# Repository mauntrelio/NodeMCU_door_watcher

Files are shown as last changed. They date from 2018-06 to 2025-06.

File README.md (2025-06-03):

# Tür Beobachtung: DIY Door Alarm System

Welcome to the Tür Beobachtung project! This is a DIY door alarm system I created in 2019 to help my in-laws keep their bike shed door securely closed during the night at their countryside retreat. Over time, I've enhanced it with new features and improvements.

## Project Overview

The Tür Beobachtung project combines hardware and software to create an effective door monitoring solution. It's designed to alert the user with both audio and visual signals if the door remains open during specific times, mostly at night. We utilize an ESP8266 microcontroller with added functionalities including notifications via Pushbullet and time synchronization from the start. Over time, improvements have included a 3D-printed box, a web interface running directly on the microcontroller, TOTP-based authentication for an HTTPS gateway, and fine-tuned alarm management.

## List of Materials

- 1 ESP8266 Microcontroller
- 1 5V Power Supply
- 1 Magnetic Sensor
- 1 Magnet
- 1 LCD Panel HD44780 with I2C Controller
- 1 Light (LED)
- 1 Voltage Booster (5V to 12V)
- 2 Transistors
- 2 Diodes
- 2 Resistors (1kΩ)
- 1 Resistor (200Ω)
- 1 Buzzer Module
- 1 LED
- 1 Main Switch
- 4 Small Switches
- Various Cables

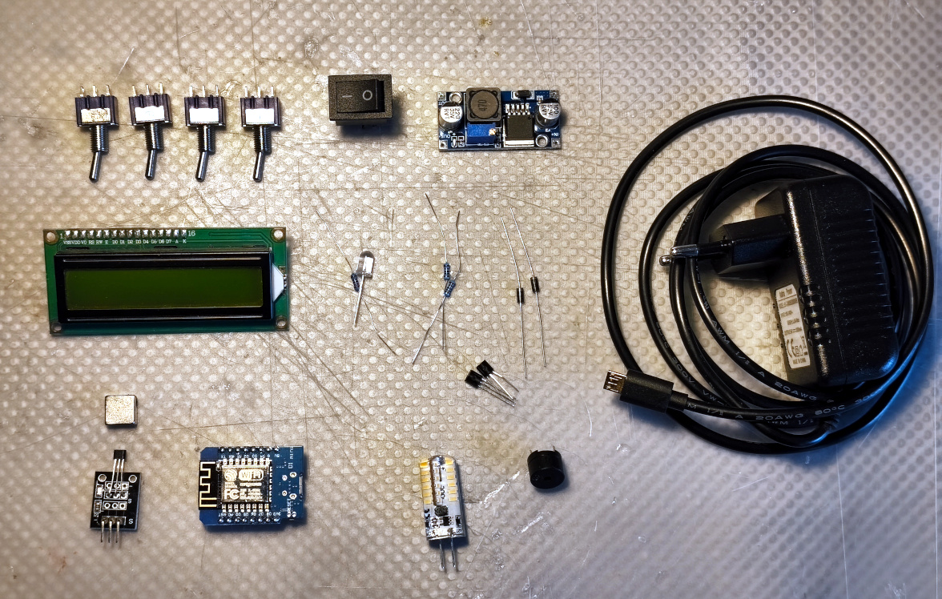
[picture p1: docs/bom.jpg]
List of Materials


## Installation and Usage

### Code and Compilation

The code for the Tür Beobachtung project is written in C and designed to be compiled and uploaded to the microcontroller using [PlatformIO](https://platformio.org/).

To be able to send Pushbullet notification without using HTTPS, a gateway server in HTTP with a PHP script sending the requests to Pushbullet in HTTPS is needed. Authentication over the unsafe HTTP channel is done via TOTP.

- **`src` folder**: Contains the source code for the microcontroller (ESP8266).
- **`web` folder**: Contains files for the web server that acts as a gateway for sending notifications via Pushbullet or to perform other HTTPS requests that the microcontroller cannot handle directly.
- **`data` folder**: Contains the file system for the web interface to be uploaded onto the microcontroller.
- **`docs` folder**: Contains some pictures of the project and the electrical schematics drawn using Fritzing.

### Electrical Schematic

The project's electrical schematic, drawn using [Fritzing](http://fritzing.org/), is included to provide a clear and organized guide to building and assembling the hardware components.

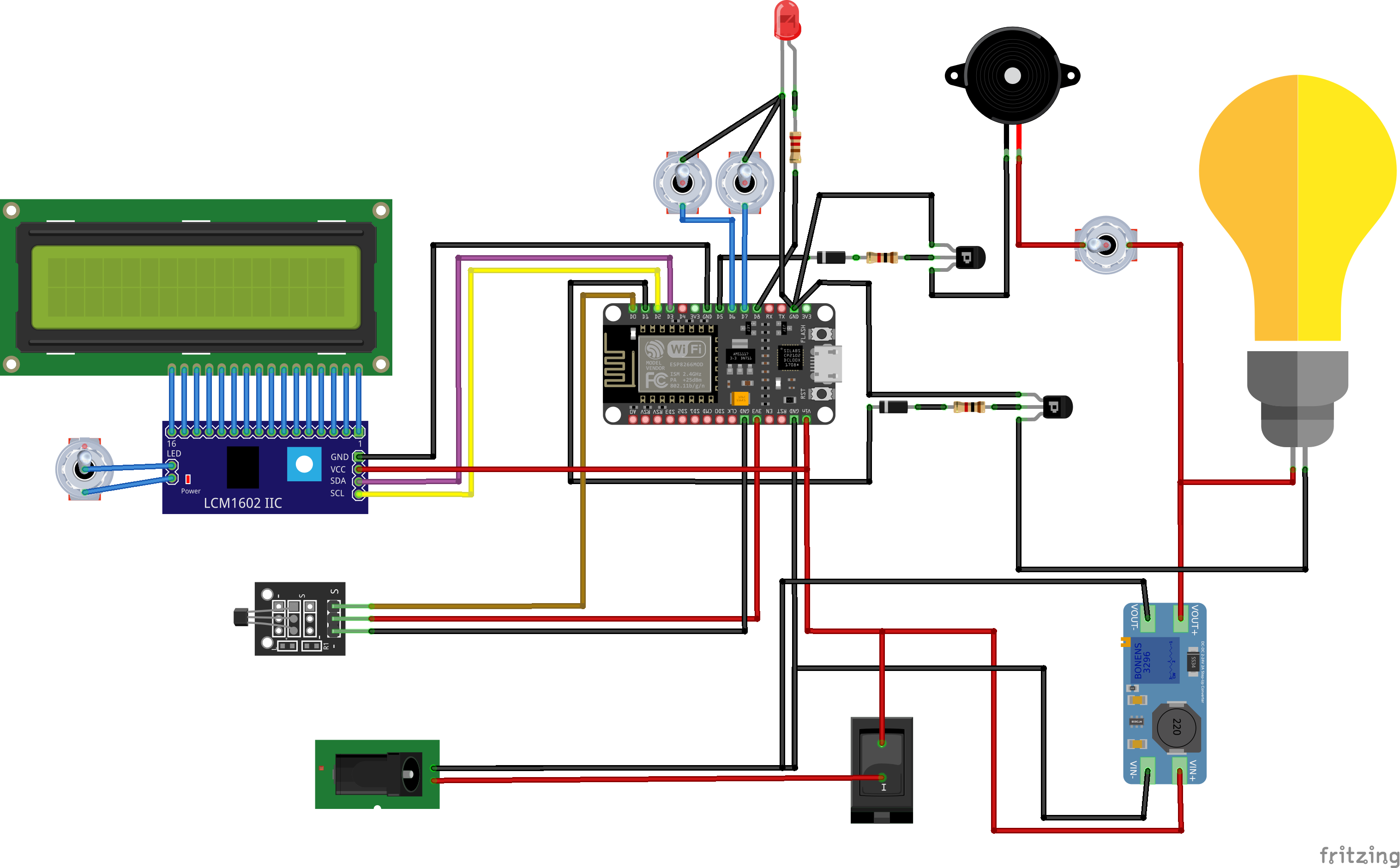
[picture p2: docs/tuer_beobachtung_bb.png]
Electrical Schematic


## Features

- **Automatic Time Synchronization**: Ensures the alarm activates at the correct hours.
- **Push Notifications**: Alerts are sent directly to your mobile device via Pushbullet if the door is left open.
- **Manual Override Switches**: Allow for manual control over the alarm system and lighting.
- **TOTP Authentication**: Adds a layer of security for server communications.

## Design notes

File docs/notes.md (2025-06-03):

# Tür Beobacthung BOM

- ESP8266 (nodeMCU)
- Alimentatore 5V
- Interruttore
- Booster 12V (per luce)
- Luce (esterna)
- Buzzer (esterno)
- 2 diode (light + buzzer switch)
- 2 x 1kOhm resistor (light + buzzer switch)
- 2 npn BJT (light + buzzer switch)
- 200Ohm resistor
- 1 red led
- 3 swicthes (alarm, light, display)
- 1 magnetic sensor
- 1 magnet
- 1 HD44780 1602 LCD Module

Connected PINs

D0, 3V (sensor, input)
D1 (light transistor, output)
D5 (buzzer transistor, output)
D2, D3 (i2c)
D6 (switch light on/off, input)
D7 (switch alarm on/off, input)
D8 (led alarm, output)

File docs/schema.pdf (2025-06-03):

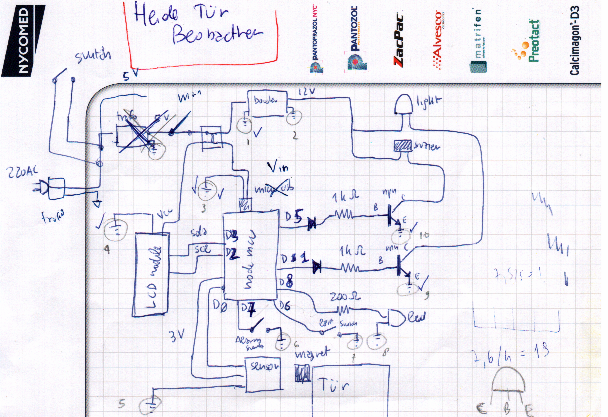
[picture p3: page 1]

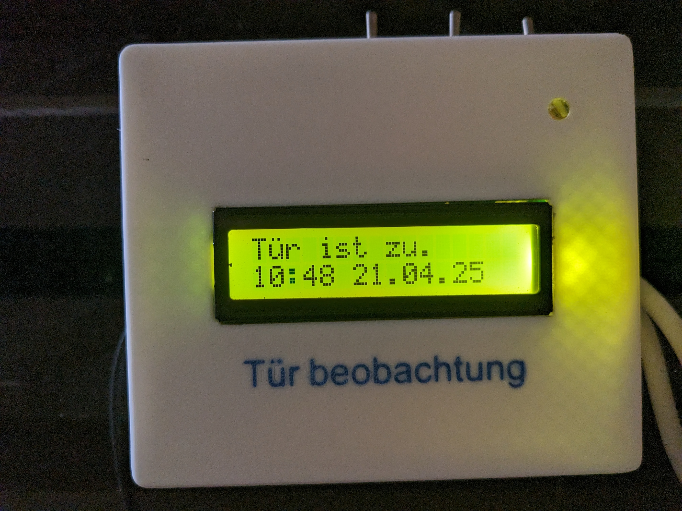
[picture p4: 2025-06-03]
docs/PXL_20250421_084856044_Mau.jpg

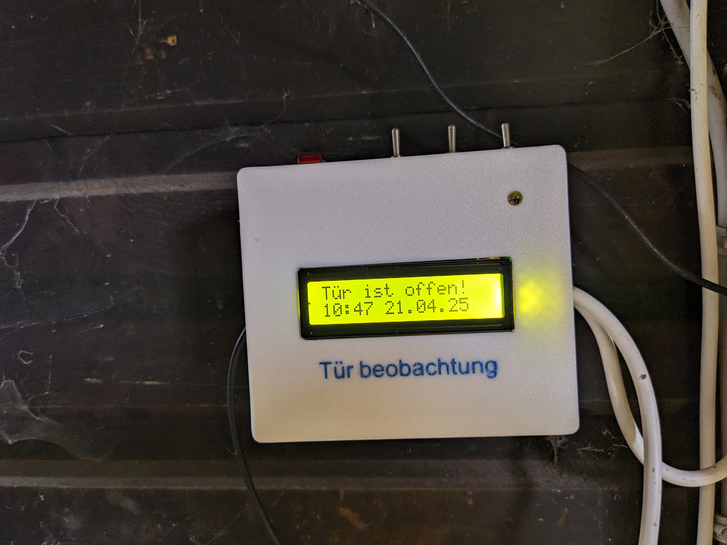
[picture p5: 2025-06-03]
docs/PXL_20250421_084728889_Mau.jpg

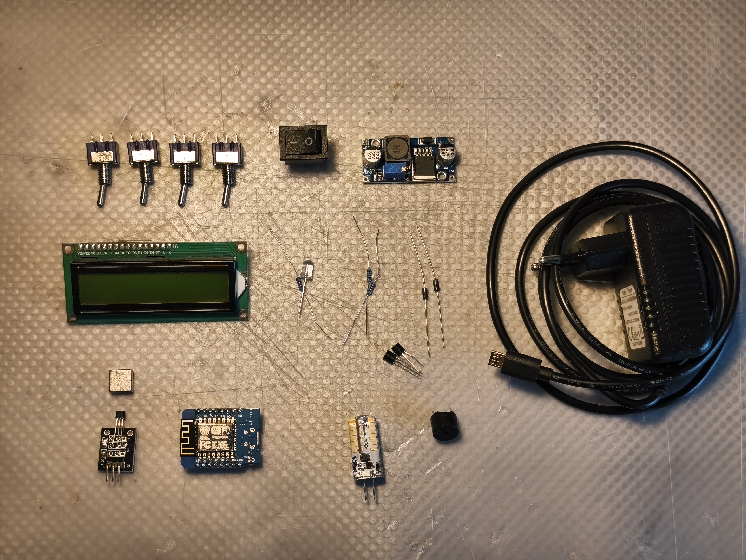
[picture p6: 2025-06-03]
docs/IMG_20250526_201353_Mau.jpg

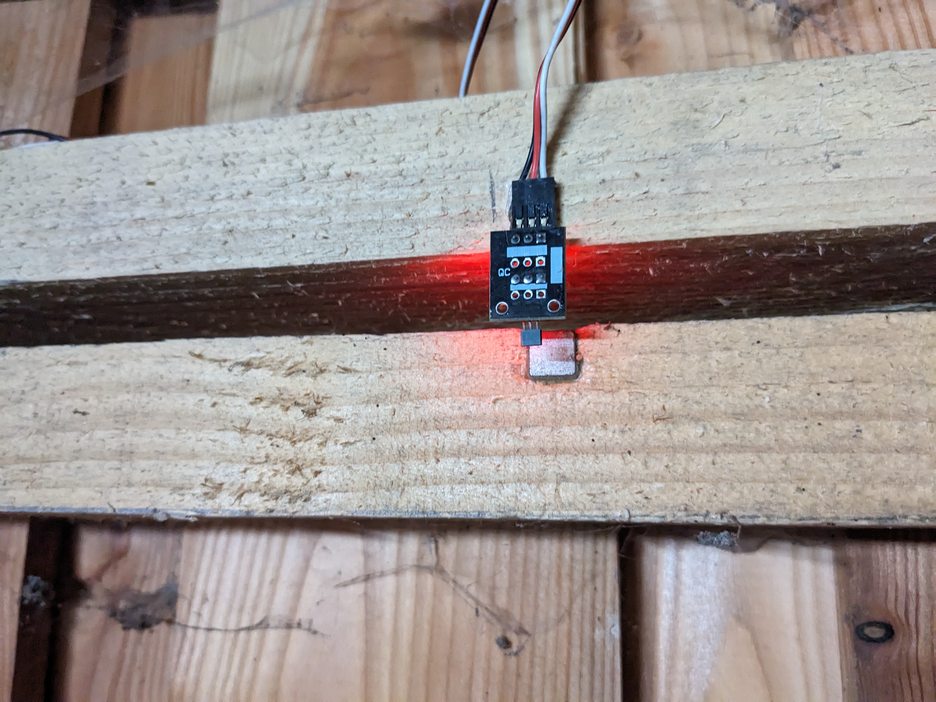
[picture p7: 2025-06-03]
docs/PXL_20250421_084847016_Mau.jpg

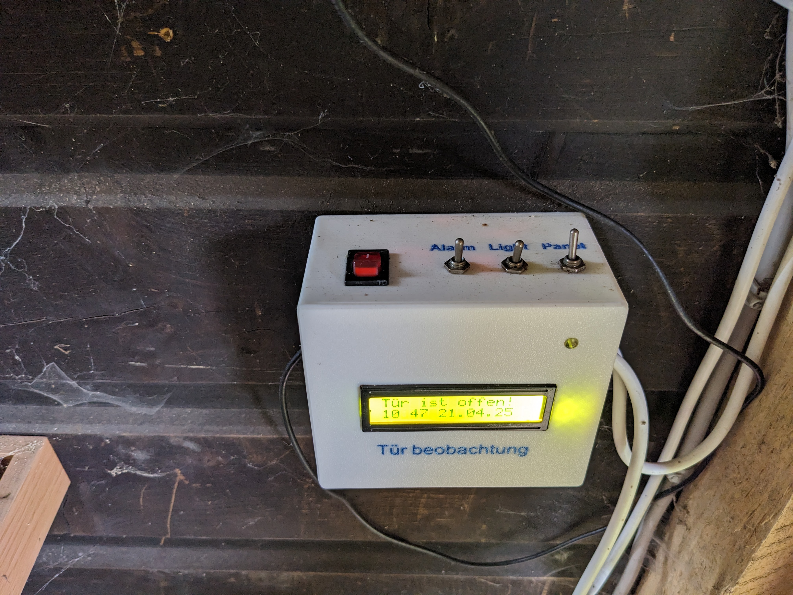
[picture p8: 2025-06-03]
docs/PXL_20250421_084733644_Mau.jpg

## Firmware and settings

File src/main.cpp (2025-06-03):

#include <Arduino.h>
#include <ESP8266WiFi.h>
#include <ESPAsyncTCP.h>
#include <ESPAsyncWebServer.h>

#include <time.h>
#include <Timezone.h>
#include <TimeLib.h>
#include <Ticker.h>
#include <TOTP.h>

#include <Wire.h>
#include <hd44780.h> // include hd44780 library header file
#include <hd44780ioClass/hd44780_I2Cexp.h> // i2c LCD i/o class header

#include "../lib/NTPSync/NTPSync.h"
#include "../lib/AsyncHTTPClient/AsyncHTTPClient.h"

#include "config.h"

// web server
AsyncWebServer server(80);
// web event source
AsyncEventSource events("/events");

IPAddress localIP;
bool ledState = false;
bool alarm_flag = false; // alarm is beeping or not
int alarm_status = 0; // unknown alarm status (0 = off, 1 = on, not in the time, 2 = on, in time, door closed, 3 = rings)
bool v_dots = false;
int door_status = -1; // unknown door status (0 = closed, 1 = open)
int clock_loops = 0;

// lcd display
hd44780_I2Cexp lcd;

// handle web request for data
char * webData()
{
  // prepare output data
  static char infoDoor[2];
  static char infoAlarm[2];
  static char json[16];
  snprintf(infoDoor, 2,"%d", door_status);
  snprintf(infoAlarm, 2,"%d", alarm_status);

  // spit out JSON with data
  strcpy(json, "{\"d\":");
  strcat(json, infoDoor);
  strcat(json, ",\"a\":");
  strcat(json, infoAlarm);
  strcat(json, "}");
  return json;
}

void urlEncode(char *string)
{
    char charToEncode;
    int posToEncode;
    while (((posToEncode=strspn(string,"1234567890ABCDEFGHIJKLMNOPQRSTUVWXYZabcdefghijklmnopqrstuvwxyz-_.~"))!=0) &&(posToEncode<strlen(string)))
    {
        charToEncode=string[posToEncode];
        memmove(string+posToEncode+3,string+posToEncode+1,strlen(string+posToEncode));
        string[posToEncode]='%';
        string[posToEncode+1]="0123456789ABCDEF"[charToEncode>>4];
        string[posToEncode+2]="0123456789ABCDEF"[charToEncode&0xf];
        string+=posToEncode+3;
    }
}

// update an output based on an input
void switching(const int input, const int output) {
  if (digitalRead(input) == HIGH) {
    digitalWrite(output, LOW);
  } else {
    digitalWrite(output, HIGH);
  }
}

// physical alarm: blink led, beep buzzer, blink LCD backlight
void blinker()
{
  digitalWrite(PIN_LIGHT, ledState);
  digitalWrite(PIN_LED, ledState);
  if (ledState) {
    lcd.backlight();
    tone(PIN_BUZZER, BUZZER_FREQ);
  } else {
    lcd.noBacklight();
    noTone(PIN_BUZZER);
  }
  ledState = !ledState;
}

// reset physical alarm
void blinkReset()
{
  Serial.println("Reset blink");
  digitalWrite(PIN_LIGHT, LOW);
  noTone(PIN_BUZZER);
  lcd.backlight();
  switching(PIN_SWITCH_0, PIN_LED);
  switching(PIN_SWITCH_1, PIN_LIGHT);
}

// timer for the blinker (active alarm)
Ticker timer_alarm(blinker, 250);

// update the status of the alarm
void updateAlarmStatus(Timezone tz)
{
  int current_alarm_status = alarm_status;
  // first check the switch
  int button = digitalRead(PIN_SWITCH_0);
  alarm_status = (button == HIGH) ? 0 : 1;

  // alarm activated, run further checks
  if (alarm_status > 0) {
    // check the time
    time_t utc = now();
    time_t local_time = tz.toLocal(utc);
    int currentHour = hour(local_time);
    // update the status based on alarm activation time and door status
    if (currentHour >= ALARM_START || currentHour <= ALARM_END) {
      alarm_status = (door_status == 0) ? 2 : 3;
    };
  }

  // emit update status event for web clients
  if (alarm_status != current_alarm_status) {
    events.send(webData(),"status",millis());
  }
}

// Function to format time with time zone
void formatTime(char *buf, const char *_fmt, Timezone tz)
{
	time_t utc = now();
	time_t local_time = tz.toLocal(utc);
  struct tm *info;
  info = localtime(&local_time);
  strftime(buf, 16, _fmt, info);
}

// Send push notification (door is open)
void sendPush()
{

  TOTP totp = TOTP(secretKey, 10);
  String authCode = totp.getCode(now());
  Serial.print("OTP:" );
  Serial.println(authCode);

  char dateTime[25];
  formatTime(dateTime, format_time, CE);
  urlEncode(dateTime);

  char requestBody[180] = "GET /services/sendalert.php";
  strcat(requestBody, "?body=");
  strcat(requestBody, dateTime);
  strcat(requestBody,"%20-%20T%C3%BCr%20ist%20offen!&title=T%C3%BCr%20Beobachtung&otp=");
  strcat(requestBody, authCode.c_str());
  strcat(requestBody, " HTTP/1.0\r\nHost: ");
  strcat(requestBody,  HOST);
  strcat(requestBody, "\r\n\r\n");
  
  Serial.print("Requesting URL: ");
  Serial.println(requestBody);
  sendHTTP(String(requestBody), HOST);
}

// Register DNS
// void registerDNS()
// {
//   char requestBody[160] = "GET /services/dns.php";
//   strcat(requestBody, "?name=");
//   strcat(requestBody, NAME);
//   strcat(requestBody, "&ip=");
//   strcat(requestBody, localIP.toString().c_str());
//   Serial.print("Requesting URL: ");
//   Serial.println(requestBody);
//   strcat(requestBody, " HTTP/1.0\r\nHost: ");
//   strcat(requestBody,  HOST);
//   strcat(requestBody, "\r\n\r\n");
//   sendHTTP(String(requestBody), HOST);
// }

// Start the alarm
void startAlarm()
{
  // alarm already running
  if (alarm_flag)
    return;

  Serial.println("Starting the alarm");
  timer_alarm.start();
  alarm_flag = true;
  sendPush();
}

// Stop the alarm
void stopAlarm()
{
  // alarm not running
  if (!alarm_flag)
    return;

  Serial.println("Stopping the alarm");
  timer_alarm.stop();
  // reset the physical alarms
  blinkReset();
  alarm_flag = false;
}

// Display current time and date in LCD
void displayTime()
{
  char buffer[16];
  formatTime(buffer, format_time, CE);
  lcd.setCursor(0,1);
  lcd.print(buffer);
  Serial.println(buffer);
}

// Update the lcd display and status of the alarm
void clockUpdate()
{
  // update the status of the alarm
  updateAlarmStatus(CE);

  // display bell if alarm is on
  lcd.setCursor(15, 0);
  (alarm_status > 1) ? lcd.print('\001') : lcd.print(" ");

  // start/stop the alarm if that is the case
  (alarm_status == 3) ? startAlarm() : stopAlarm();

  // check the switches
  switching(PIN_SWITCH_0, PIN_LED);
  switching(PIN_SWITCH_1, PIN_LIGHT);

  // update the clock display every 15 seconds
  if (clock_loops == 0) {
    displayTime();
  }

  lcd.setCursor(2, 1);
  // blink the ":" between hour and minute every half second
  (v_dots) ? lcd.write(":") : lcd.print(" ");
  v_dots = !v_dots;
  clock_loops++;

  if (clock_loops == 30)
    clock_loops = 0;
}

// timer for the clock update
Ticker timer_clock(clockUpdate, 500);

// Read the door sensor
void sensor()
{
  int val = digitalRead(PIN_SENSOR);
  if (val == HIGH && door_status != 1) {
    lcd.home();
    lcd.print("T\xF5r ist offen!");
    Serial.println("Door is open!");
    door_status = 1;
    events.send(webData(),"status",millis());
  } else if (val == LOW && door_status != 0) {
    lcd.home();
    lcd.print("T\xF5r ist zu.   ");
    Serial.println("Door is closed!");
    stopAlarm();
    door_status = 0;
    events.send(webData(),"status",millis());
  }
}

// setup
void setup()
{

  // set up the web server
  // Initialize SPIFFS
  SPIFFS.begin();
  // web server routes
  server.serveStatic("/", SPIFFS, "/").setDefaultFile("index.html");
  server.on("/data", HTTP_GET, [](AsyncWebServerRequest *request){
    request->send(200, "application/json", String(webData()));
  });  

  pinMode(PIN_LED, OUTPUT);
	pinMode(PIN_LIGHT, OUTPUT);
	pinMode(PIN_SENSOR, INPUT_PULLUP);
  pinMode(PIN_SWITCH_0, INPUT_PULLUP);
  pinMode(PIN_SWITCH_1, INPUT_PULLUP);

  Serial.begin(9600);

  // initialize i2c lcd
	Wire.begin(PIN_SDA, PIN_SCL);
	Wire.beginTransmission(I2C_ADDR);
  while (! Serial);
	lcd.begin(16, 2);
  lcd.setBacklight(255);
  lcd.clear();
	Serial.println("Starting...");
	lcd.print("Starting...");
  lcd.createChar(1, bell);

  // initialize WiFi
  WiFi.mode(WIFI_STA);
  WiFi.begin(SSID, PASS);
	Serial.print("Connecting to "); Serial.println(SSID);
	lcd.home();
	lcd.print("Connect "); lcd.print(SSID);
	lcd.setCursor(0, 1);
  int counter = 0;
  while (WiFi.status() != WL_CONNECTED) {
    delay(500);
    Serial.print(".");
		lcd.print(".");
    counter++;
    if (counter == 17) {
      lcd.clear();
      lcd.print("Connect "); lcd.print(SSID);
      lcd.setCursor(0, 1);
      counter = 0;
    }
  }

  localIP = WiFi.localIP();

  lcd.clear();
  lcd.print("Connected! IP:");
  lcd.setCursor(0, 1);
  lcd.print(localIP.toString());

  Serial.println("");
  Serial.println("WiFi connected");
  Serial.println("IP address: ");
  Serial.println(localIP.toString());

  // register to the DNS
  // registerDNS();

  // initialize time sync
  setSyncProvider(getNtpTime);
  setSyncInterval(SYNC_INTERVAL);

	delay(2000);
  lcd.clear();

  // start the clock
  timer_clock.start();

 // start the web server
 server.addHandler(&events);
 server.begin();

} // setup()

// loop
void loop()
{
  timer_clock.update(); // the clock
  timer_alarm.update(); // blinks the alarm (if running)
  sensor(); // the door sensor
} // loop()

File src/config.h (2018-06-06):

#include <pins_arduino.h>

const int I2C_ADDR = 0x3F;

const int PIN_SENSOR = D7;
const int PIN_LIGHT = D0;
const int PIN_SCL = D2;
const int PIN_SDA = D3;
const int PIN_BUZZER = D5;
const int PIN_SWITCH_0 = D6;
const int PIN_SWITCH_1 = D1;
const int PIN_LED = D8;

const int BUZZER_FREQ = 2500;
const int ALARM_START = 12;
const int ALARM_END = 7;
const int SYNC_INTERVAL = 7200;

const char* HOST = "*******";

const char* SSID = "*******";
const char* PASS = "*******";

const char* format_time = "%H:%M %d.%m.%y";
// char format_date[] = "%a %d %b %Y";
// char format_date[] = "%d/%m/%Y T\xF5r";

// Central European Time (Berlin, Rome)
TimeChangeRule CEST = {"CEST", Last, Sun, Mar, 2, 120};  // Central European Summer Time
TimeChangeRule CET = {"CET ", Last, Sun, Oct, 3, 60};    // Central European Standard Time
Timezone CE(CEST, CET);

// custom char for bell
uint8_t bell[8]  = {0x04,0x0e,0x0e,0x0e,0x1f,0x00,0x04,0x00};
